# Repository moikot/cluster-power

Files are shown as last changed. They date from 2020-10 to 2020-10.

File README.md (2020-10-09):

# Cluster power

Two PCBs designed to provide Raspberry Pis or similar single-board computers with 5V and up to 3A current. 

[Power board](#power-board)  
[Power bridge](#power-bridge)  

## Power board

A circuit diagram and a PCB design for a modular power supply. It's based on a DC-DC step-down voltage buck converter module and can supply a Raspberry Pi or a similar single-board computer with 5V and up to 3A current. 

You can connect several power boards in a chain using [AVX bipolar card edge connector Series 9159](https://no.mouser.com/ProductDetail/581-00915900201106) and provide power to a cluster of Raspberry Pis. 

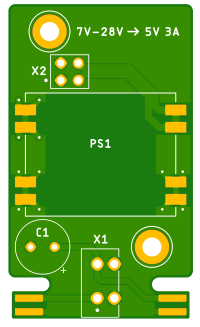
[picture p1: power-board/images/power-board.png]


### Technical characteristics

* Input voltage: 7V-28V DC
* Output voltage: 5V DC
* Output current: 3A. max (2A for a long time)

### Components

* 3 x 7V-28V to 5V DC-DC step-down voltage buck converter [module](https://www.aliexpress.com/item/32728471522.html).
* Fixed Terminal Block [PTSM 0,5/ 2-2,5-H](https://no.mouser.com/ProductDetail/651-1770885).
* 2 postions x 2 rows [board to board connector](https://no.mouser.com/ProductDetail/200-SSW10201GD).
* 100µF 50V Aluminum [electrolytic capacitor](https://www.digikey.no/product-detail/en/panasonic-electronic-components/ECA-1HM101/P5182-ND/245041).

## Power Bridge

A circuit diagram and a PCB design for a small board for connecting  [Power board](#power-board)  to a Raspberry Pi or a similar single-board computer and providing power through its GPIO.



### Components
* 2 postions x 2 rows right angle [header](https://no.mouser.com/ProductDetail/200-TSW10208LDRA).
* 5 postions x 2 rows [board to board connector](https://no.mouser.com/ProductDetail/200-SSW10501GD).

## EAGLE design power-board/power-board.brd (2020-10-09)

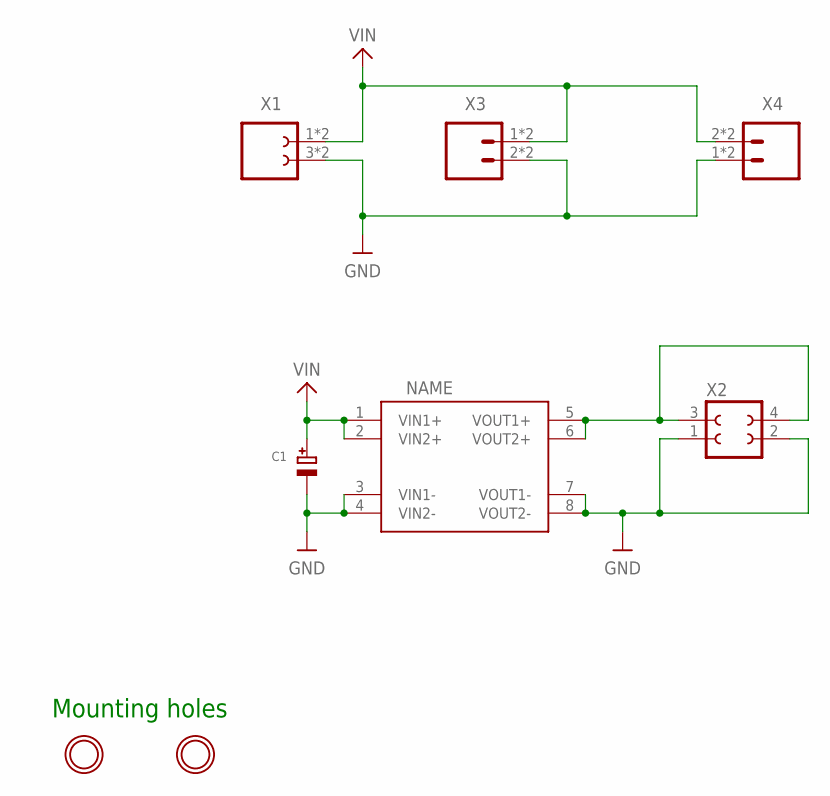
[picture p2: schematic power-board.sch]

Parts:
C1: CAP_ELECTROLYTIC; CAPPRD350W60D800H800B
PS1: K8801MODULE; K8801
U$2, U$3: MOUNTINGHOLE2.7_THICK; MOUNTINGHOLE_2.7_PLATED_THICK
X1: CON-FE02-1; PTSM0,5/2-2,5-HTHRR24
X2: CON-FE02-2HDRVR4W64P254_2X2; HDRVR4W64P254_2X2
X3, X4: CON-MA02-1; AVX-BTB-009159002001106

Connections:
GND: C1.2 (-), PS1.3 (VIN1-), PS1.4 (VIN2-), PS1.7 (VOUT1-), PS1.8 (VOUT2-), X1.3, X1.4 (3), X2.1, X2.2, X3.2 (4), X3.4, X4.1 (2), X4.3 (2)
unnamed: PS1.5 (VOUT1+), PS1.6 (VOUT2+), X2.3, X2.4
VIN: C1.1 (+), PS1.1 (VIN1+), PS1.2 (VIN2+), X1.1, X1.2 (1), X3.1 (2), X3.3 (2), X4.2 (4), X4.4

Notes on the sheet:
Mounting holes

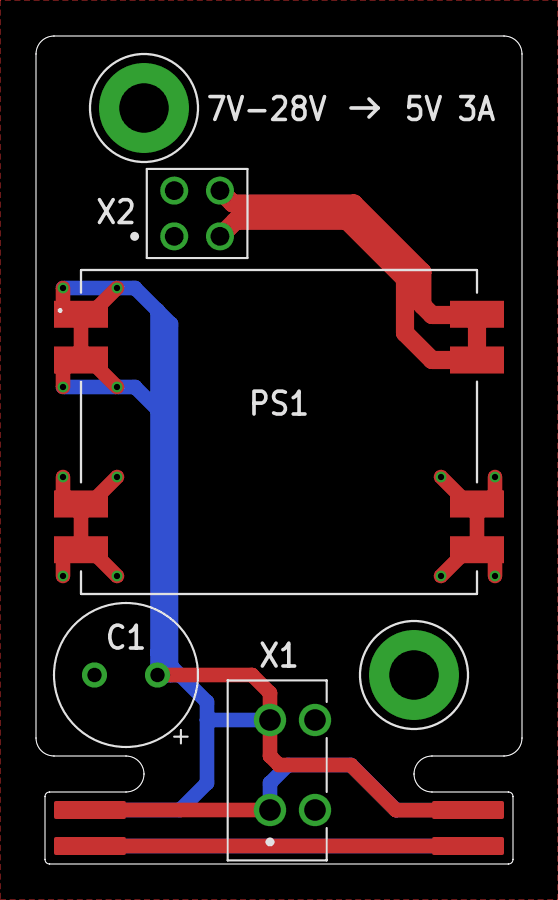
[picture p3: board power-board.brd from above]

Board: 2 copper layers, 27.0 x 46.0 mm, 8 parts (0 on the bottom side), 3 nets.

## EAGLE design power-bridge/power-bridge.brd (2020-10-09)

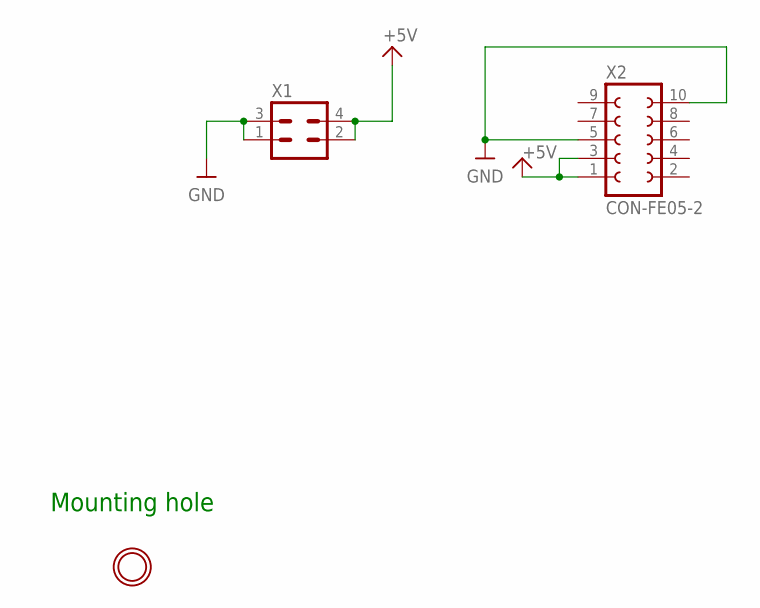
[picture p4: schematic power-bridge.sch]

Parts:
U$1: MOUNTINGHOLE2.7_THICK; MOUNTINGHOLE_2.7_PLATED_THICK
X1: CON-MA02-2; HDRRA4W64P254_2X2_508X254X556B
X2: CON-FE05-2; HDRVR10W64P254_2X5_1270X508X850B

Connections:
+5V: X1.2, X1.4, X2.1, X2.3
GND: X1.1, X1.3, X2.5, X2.10

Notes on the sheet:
Mounting hole

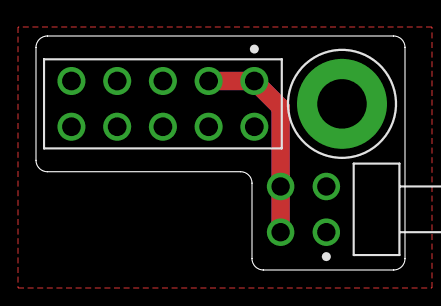
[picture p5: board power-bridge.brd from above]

Board: 2 copper layers, 20.5 x 13.0 mm, 3 parts (0 on the bottom side), 2 nets.

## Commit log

2019-11-17 Use GitHub URL instead of revision
    [power.brd]
2019-11-17 Add QR code
    [power.brd]
2019-11-17 Add a curious cat
    [power.brd]
2019-11-17 Add smiles
    [power.brd, power.sch]
2019-12-04 Add power connector
    [power-board.brd, power-board.sch, power-con.brd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]
2020-01-09 Add Power-Hat
    [power-board.brd, power-board.sch, power-hat.brd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]
2020-01-11 Add power bridge
    [power-bridge.brd, power-bridge.sch]
2020-01-11 Add power slot
    [power-slot.brd, power-slot.sch]
2020-01-12 Finalize Power slot
    [power-bridge.brd, power-bridge.sch, power-slot.brd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]
2020-01-12 Board outline fix
    [power-slot.brd]
2020-02-04 Add power bridge v3
    [power-bridge.brd, power-bridge.sch]
2020-02-08 Add a new version of Power Slot
    [power-slot.brd, power-slot.sch]
2020-08-23 Add v4 bridge and v3 powers slot
    [power-bridge.brd, power-bridge.sch, power-slot.brd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]
2020-10-09 Publish v1.0.0 Power Board and Power Bridge
    [power-board.brd, power-board.sch, power-bridge.brd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]
